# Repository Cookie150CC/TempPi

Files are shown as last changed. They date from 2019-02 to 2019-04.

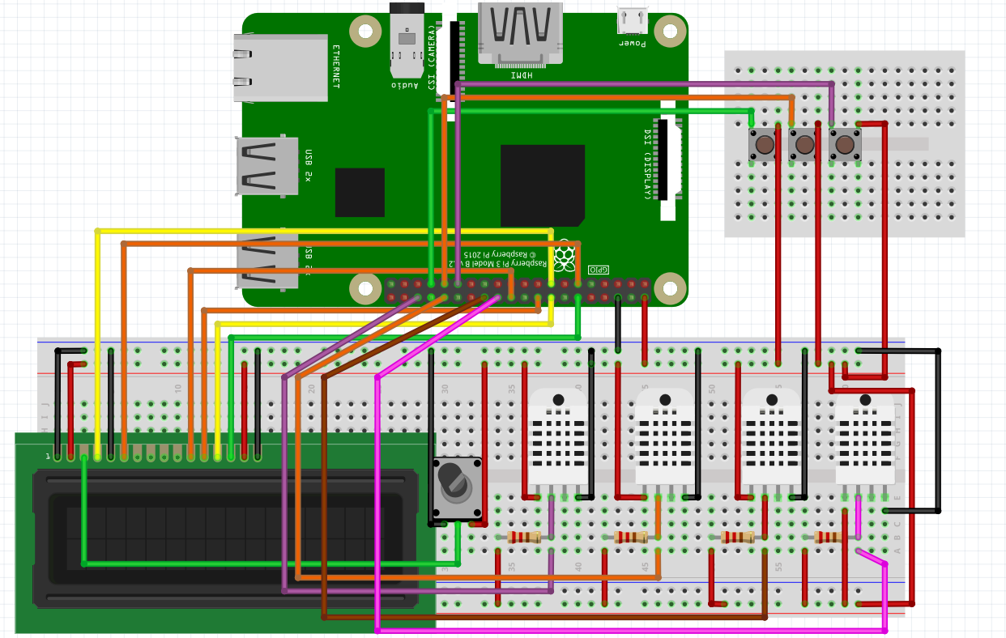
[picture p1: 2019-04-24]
Diagrams and Models/Wiring Diagram/Wiring Diagram.PNG

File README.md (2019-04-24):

# TempPi
- A server room temperature sensor system.
- This program was create for a Raspberry Pi model 3 b+

## WorkFlow
1. When adding a feature Create a new branch for your feature using "git checkout -b <name of your new branch>"
2. When done use push up your branch using "git add <name(s) of added files>" "git commit -m 'MSG'" "git push"
3. Then create a pull request to merge your changes with the master branch. [click here](https://github.com/Cookie150CC/TempPi/pulls) 
  
## Python Programming Standards
- Please read the PEP 8 programming standard before submitting any python code to the repository.
- [PEP-8 programming standard](https://www.python.org/dev/peps/pep-0008/#maximum-line-length)
- Pyhton 3 will be used exclusively

## Install
- To ensure proper functionality please clone this directory into ~/Source on the Raspberry Pi file system.
- To use the Adafruit_Python_DHT sensor library. The directory can be found [here](https://github.com/adafruit/Adafruit_Python_DHT). Then run the setup.py script to install on the Raspberry Pi
- For used wiring please reference [here](https://github.com/Cookie150CC/TempPi/blob/master/Spikes/RaspberryPi_v01_WiringSchematic.pdf) in the Spikes directory
- For real time clock integration please reference [here](https://github.com/Cookie150CC/TempPi/blob/master/Spikes/Spike%20on%20RTC%20integration.md)

## WebApp for project
- Reference [this repository](https://github.com/yillivs/Pi-Webapp).

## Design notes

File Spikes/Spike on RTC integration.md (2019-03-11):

# RTC PF8523
- [Datasheet](https://www.nxp.com/docs/en/data-sheet/PCF8523.pdf)

### For wiring, i2c configuration, setting up the pi on RTC time, and RTC time synchronization use [this](https://pimylifeup.com/raspberry-pi-rtc/) as a reference.

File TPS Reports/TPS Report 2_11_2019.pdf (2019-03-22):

TPS Report
2/11/19
Brittain Cooke
Grant Gannon
Oliver Sanchez
| Task | Time Estimate | Risk | Who | Review
| Spikes On SMS From PI | 2 Days | 4 | All | One of the project requirements is being able to send a text alert to our administrative user alerting them in the event of a temperature spike. We went and tried to find our best and most cost effective solution for this project.
| Spike on Logging Temp | 2 Days | 3 | BC | Worked on getting the PI to periodically record the ambient temperature. This too is a project requirement set by our client. It's also critical for our future web app implementation
| Integrating RTC | 2 Days | 3 | BC/OS | Integrating the Real Time Clock will allow us to track time even when the real time server it checks in with is down. The RTC will be critical for gauging blackout time which we then can log.
| Look into more case solutions | 2-4 Days | 2 | GG | At this point we're going forward with designing our case, the biggest thing to consider is how to attach the screen onto the case.
| Review Stories and TPS Reports | 1 Day | 2 | All | Keep files organized and accessible

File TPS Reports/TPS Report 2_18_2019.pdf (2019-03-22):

TPS Report
2/18/19
Brittain Cooke
Grant Gannon
Oliver Sanchez
| Task | Time Estimate | Risk | Who | Review
| Created a physical control | 2-3 Days | 3 | BC | Added some options to be added using the physical controls, this let's the user change settings without remoting in to the pi itself.
| Work on remote accessibility | 2 Days | 3 | BC | Worked on ssh functions of the project. Allowing us to remotely poll the pi for the temperature. Will be critical for future implementation of the user site.
| Spike on WebApp Design | 2 Days | 3 | OS | Working through to decide what our options are for our browser app/access. Worked on making/finding our stye guide for the site to follow. Also worked on finding a method to recieve the data from the pi to then be able to display
| Case Design | 2-4 Days | 2 | GG | Worked on a test iteration of the case design using maya Autodesk, which consisted of the housing for the PI along with mounting for the screen. The major downside is that it's still not housing all the components but not sure if this can be helped.
| Review Stories and TPS Reports | 1 Day | 2 | All | Keep files organized and accessible

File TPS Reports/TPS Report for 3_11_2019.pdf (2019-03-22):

TPS Report

3/11/19

Brittain Cooke

Grant Gannon

Oliver Sanchez

| Task | Time Estimate | Risk | Who | Review
| Permanent Wiring Solution Spike | 2 Days | 2 | GG/BC | For the final product we're going to want something nicer than a breadboard to connect our devices and sensors. A PCB is a possible alternative to sawed down breadboard.
| Case Research Cont. | 2 Days | 1 | GG/BC | The search for a case not only for the PI but the components continues. Now that final constraints are available a case is in developement
| Adding Unittesting | 2 Days | 3 | BC | Pythons unittest library has been utilized to create unit test for all funcitons. Test will be continuously added now as new funcitons are made [1]
| Converting program to object oriented approach 4 Days | | 4 | BC/OS | The program was reorganized as an OOP for readability, security, and maintanability.
| General Wiring Scematic | 1 Day | 2 | OS | After the re-wire, the need for a schematic became clear if we would want to easily make another one.
| WebApp services create | 2 Day | 2 | OS | Keep files organized and accessible. Merge development branch with our production branch. Created service classes to manage authentication tasks like retreiving authentication tokens and http requests.

### [1] sadf

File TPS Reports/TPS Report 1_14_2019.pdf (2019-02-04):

TPS Report

1/14/19

Brittain Cooke

Grant Gannon

Oliver Sanchez

| Task | Time Estimate | Risk | Who | Review
| Find a python programming standard agreeable to all | 2-4 Days | 3 | All | Important to ensure team members are all writing in same style/format
| Prep Raspberry Pi | 1 Day | 2 | BC | Get the device prepared with some simple operating system, to be able to start testing when parts arrive
| Begin research on on-campus 3d printing solutions | 1 Day | 2 | BC | Maker Spaces at library/Computer Club/Ordering
| Review Stories and TPS Reports | 1 Day | 2 | All | Keep files organized and accessible

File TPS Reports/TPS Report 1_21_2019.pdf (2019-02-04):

TPS Report
1/21/19
Brittain Cooke
Grant Gannon
Oliver Sanchez
| Task | Time Estimate | Risk | Who | Review
| Implement Screen | 1-2 Days | 4 | BC | Implement screen to raspberry pi to output basic text
| Spike on Temp Probes | 2-3 Days | 3 | All | Measure accuracy of our ordered temperature probe compared to 'actual' temperature
| Spike on PI Operating system | 1 Day | 2 | GG | Finalize our decison on what operting system to use
| Review Stories and TPS Reports | 1 Day | 2 | All | Keep files organized and accessible

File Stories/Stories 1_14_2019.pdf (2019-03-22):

Brittain Cooke
Grant Gannon
Oliver Sanchez

Stories

1) Create a device that acts as a temperature monitor for a server room: Features:
-Read room temperature using a raspberry pi and sensors -Periodically record and store temperature
-Show status using an led light based on temp
-show current temp values on the device using a display -Get humidity reading from the sensors
-AC Powered
-Connected by Wifi
2) Allow a server administrator to remotely view temps and interact with the device
Features:
-Allow an admin to SSH on to the device
-create a web app to allow users to view temperature and status -allow admin to view system logs
-be able to dump output log
-be able to modify log(add, delete, move, and search)
-be able to add and remove users from registry
3) Setup an alert system for admins if temperature exceeds limits Features:
-Send SMS text to admin when the temperature is out of range. -Allow admin to edit the thresholds for alerts
-Allow admins to edit the users to notify for these alerts
4) Create a case for the device to be contained Features:
-Make a 3D printed case to accommodate the raspberry pi

5) Device must be able to perform adequately in atypical power conditions Features:
-Device should be able to perform a safe shutdown in event of brown/blackout
-Device will reboot and log time it was offline for after a shutdown -Battery backup to ensure it can shutdown during complete blackout

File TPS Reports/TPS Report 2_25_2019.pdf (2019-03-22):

TPS Report
2/25/19
Brittain Cooke
Grant Gannon
Oliver Sanchez
| Task | Time Estimate | Risk | Who | Review
| Real Time Clock integration | 2-3 Days | 3 | BC | Real time clock added and selected to sync with Westerns time server
| Physical inteface | 2 Days | 2 | BC | Worked on overall design and control of the interface and physical interaction
| SMS over text messaging | 2 Days | 3 | All | The function to send out an email to any of the major carriers has been fleshed out all that's left is to implement into the project at large. The required information to send out a text is their phone number and carrier to be able to send out a message
| Web App | 3-4 Days | 4 | OS | Continued work on web app, currently hosted on a separate testbed could be implemented onto the PI or onto a seperate server. Styling and login services are still wip. Stpes to add users and admins have been added in.
| 3D Modeling Software | 2-4 Days | 2 | GG | Investegated other modeling software options because of the learning curve that's imposed by Maya Autodesk. Other solutions such as windows 3d builder, CAD, and blender. CAD seems like the ideal choice, but shares a lot of the challenges that Maya does. Windows 3d builder and blender don't have nice ways to implement actual scale
| Review Stories and TPS Reports | 1 Day | 2 | All | Keep files organized and accessible

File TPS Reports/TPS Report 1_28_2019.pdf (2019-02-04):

TPS Report
1/28/19
Brittain Cooke
Grant Gannon
Oliver Sanchez
| Task | Time Estimate | Risk | Who | Review
| Get Temperature to output Formatted on Screen | 2 Days | 3 | All
| Python Unit Testing Spike | 3-4 Days | 5 | All | What is it, and how do we do it: Unittest and other modules
| Implement ssh to connect with PI | 1 Day | 2 | OS | Being able to access remotely is a top priority
| Review Stories and TPS Reports | 1 Day | 2 | All | Keep files organized and accessible

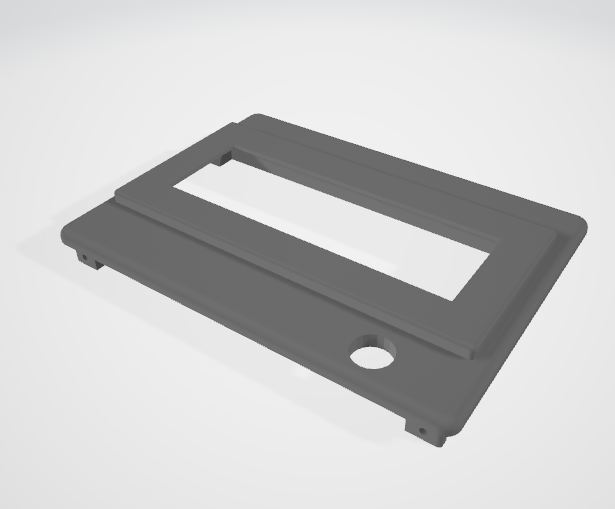
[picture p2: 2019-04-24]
Diagrams and Models/Case Design/Case Lid V2.PNG

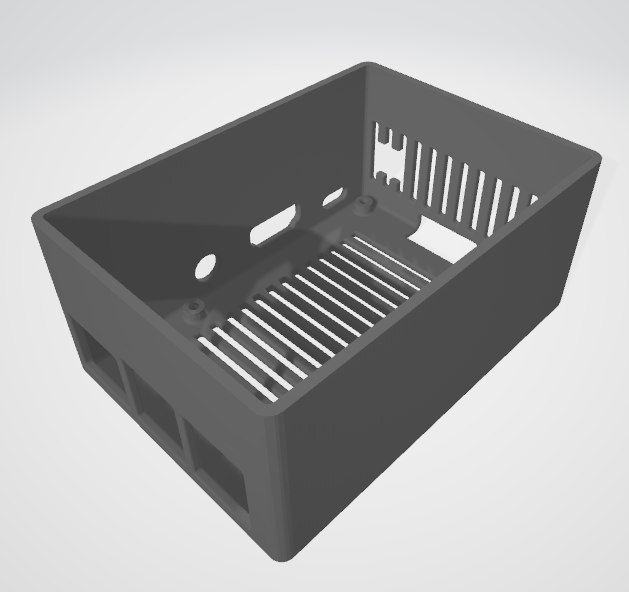
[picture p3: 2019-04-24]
Diagrams and Models/Case Design/Case Base V2.PNG

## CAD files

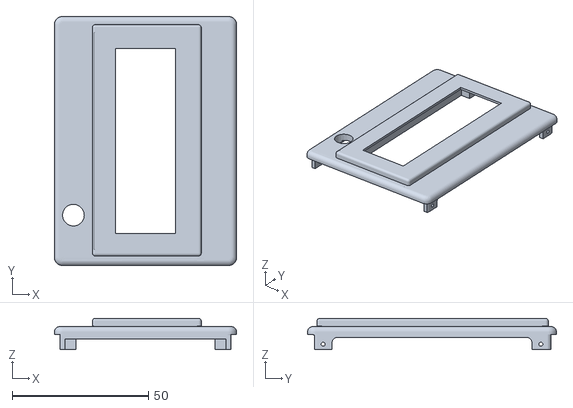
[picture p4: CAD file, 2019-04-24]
Diagrams and Models/Case Design/Case Lid V2.stl
67.0 x 91.5 x 11.5

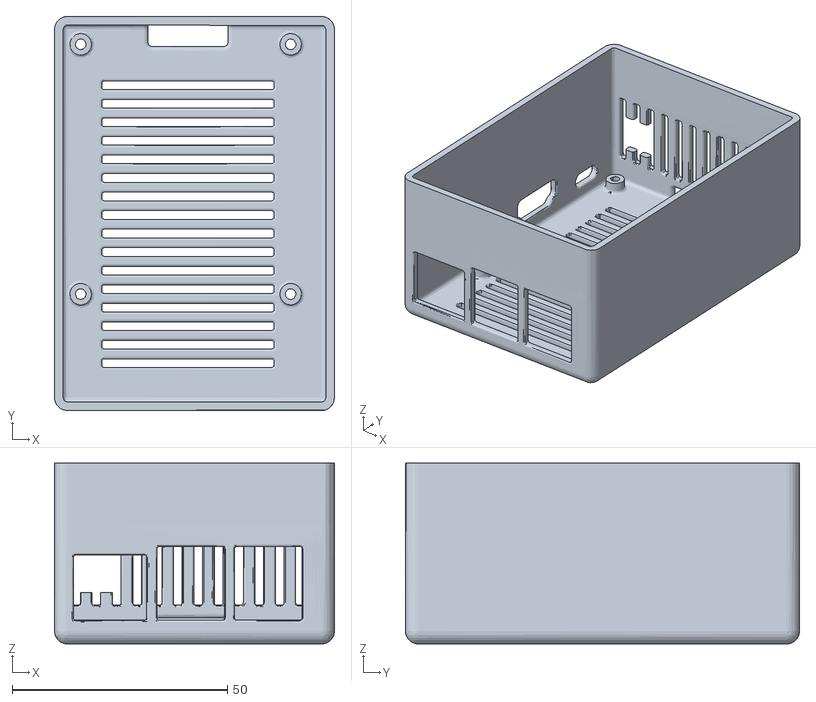
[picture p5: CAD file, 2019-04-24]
Diagrams and Models/Case Design/Case Bottom V2.stl
65.0 x 91.5 x 42.0

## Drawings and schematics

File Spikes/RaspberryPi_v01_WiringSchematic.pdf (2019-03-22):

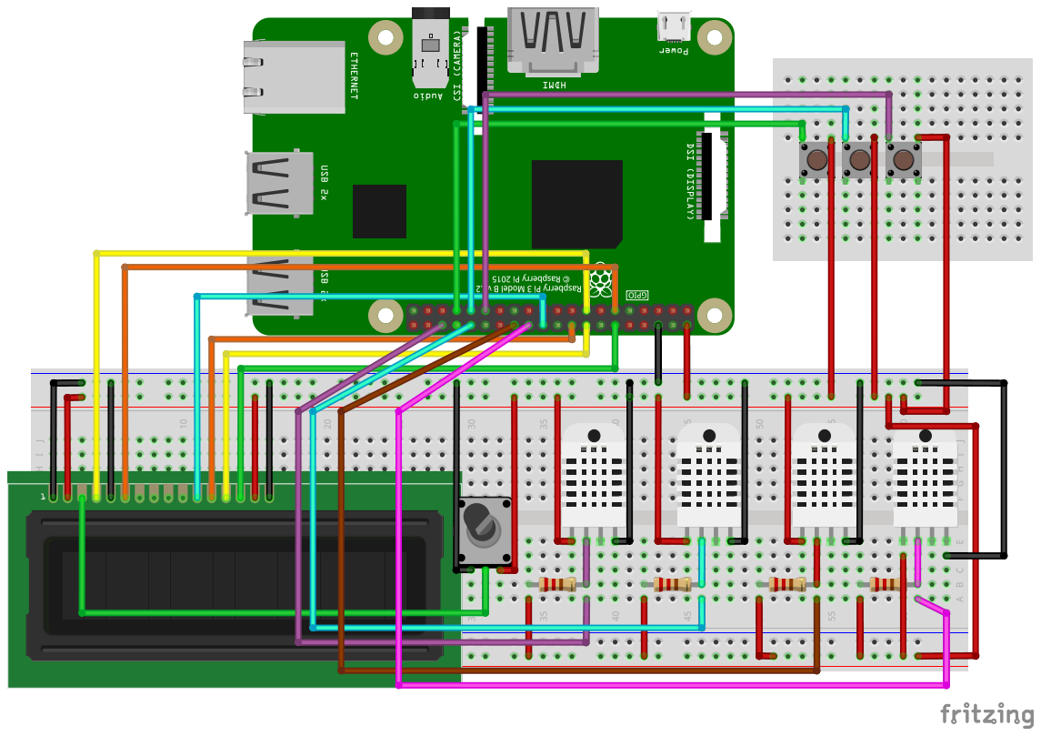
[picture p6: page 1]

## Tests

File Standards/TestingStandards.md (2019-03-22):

# Testing Standards

## Unit tests for python
- Pythons native unittest library will be used for testing of individual functions
- Documentation for pythons unittest library can be found [here](https://docs.python.org/3/library/unittest.html)
- To automate test set up the following cron job 0 0 * * * python /home/pi/Source/tests.py >> /home/pi/Source/TempPi/Source/test_logs.txt 2>&1

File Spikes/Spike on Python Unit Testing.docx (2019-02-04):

Brittain Cooke

Grant Gannon

Oliver Sanchez

Python Unit Testing

Brief: Just like in the Quad-Solver project we will need to implement some form of unit testing. For obvious reasons we will not be able to use CUnit for our python program. The goal of this spike is to identify a unit testing framework that is widely accepted, and easy to implement for our room monitoring system.

Unittest: the inbuilt python unit testing module. The good things about is that it’s supported and developed by python themselves, and it’s the recommended package by Kent Beck! The author of our Extreme Programming book. It works similar to CUnit with similar structure for testing, with the obvious difference that they’re more like python functions opposed to C(Not really a surprise though). The test still need to be predefined and aren’t usually run as one off inline commands.

Pytest: A third party solution for unit testing, the major difference between Pytest and unittest is that it’s a lot more lightweight solution. Pytest is much more a fast inline implementation, probably useful for testing a small handful of modules.The major downside with it is when it comes time for automation testing. Pytest tests aren’t really structured or made to be all strung together for large automation testing.

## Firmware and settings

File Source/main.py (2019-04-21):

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
#    You should have received a copy of the GNU General Public License
#    along with this program.  If not, see <http://www.gnu.org/licenses/>.
__author__ = "Brittain Cooke"

#imports
import sys
import RPi.GPIO as GPIO
import LiquidCrystalPi as lcrys
import time as time 
import datetime
import socket
import threading

import Config
import TSensor
import Messenger
import Display

#Varables and declarations

configObj = Config.Config()
configObj.openJSON()
tSensorObj = TSensor.TSensor()
messengerObj = Messenger.Messenger()
displayObj = Display.Display()
option = 0  #display option 
threshold = configObj.threshold  # temp threshold
oldIP = '0.0.0.0' #Default IP
logInterval = configObj.logInterval# Number of seconds between logs
sendFlag = True # Use to send temp alert messages with a break in between
sendInterval = configObj.sendInterval *60 # Number of seconds between sending temp alearts

#General GPIO Setup
GPIO.setmode(GPIO.BOARD)
GPIO.setwarnings(False)

#LCD setup
lcd = lcrys.LCD(15, 11, 22, 18, 16, 12)
lcd.begin(16,2)

#button
def buttonPress(channel):
    global option 
    option += 1
    if option >3:
        option =0

#Button setup
GPIO.setup(31, GPIO.IN, pull_up_down= GPIO.PUD_UP)
GPIO.add_event_detect(31, GPIO.FALLING, callback=buttonPress, bouncetime=400)

#logs
def writeLogs(tSensorObj):
    t,h = tSensorObj.getAvgTemp()
    dT = datetime.datetime.now()
    with open("/home/pi/Source/TempPi/Source/temp_logs.txt", "a+") as logs:
        logs.write(dT.strftime("%Y-%m-%d %H:%M:%S | "))
        if t is not None and h is not None:
            logs.write('Temp={0:0.1f}*F, Humidity={1:0.1f}%\n'.format(t,h))
        else:        
            logs.write('Failed to get reading.')
    threading.Timer(logInterval, writeLogs,[tSensorObj]).start()

#Main Loop
def doMain():

    if isinstance(threading.current_thread(), threading._MainThread): #Main thread only
        while True:
            t,h = tSensorObj.getAvgTemp()
    
            if option == 0: #Avg Temp
                msg = [t,h]
                displayObj.doDisplayOptions(option,msg)
            elif option == 1: #Sensor 0 Temp
                t,h = tSensorObj.getTemp(0)
                msg = [t,h,0]
                displayObj.doDisplayOptions(option,msg)
            elif option == 2: #Sensor 1 Temp
                t,h = tSensorObj.getTemp(1)
                msg = [t,h,1]
                displayObj.doDisplayOptions(option,msg)
            elif option == 3: #IP
                msg = [oldIP]
                displayObj.doDisplayOptions(option,msg)
        
            global sendFlag
            if t > threshold and sendFlag is True:
                messengerObj.sendMsg(configObj,t)
                sendFlag = False
                threading.Timer(sendInterval, doMain).start()   
    
    if not isinstance(threading.current_thread(), threading._MainThread): #Child thread only
        sendFlag = True


# End of main loop

writeLogs(tSensorObj)#Start logs writing
doMain()#Start main display loop

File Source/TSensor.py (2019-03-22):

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
# The program is made to use DHT22 temperature sensors

#This Library is made by Adafruit under the MIT liscense. The code can be found at https://github.com/adafruit/Adafruit_Python_DHT
import Adafruit_DHT as _dht


class TSensor():
 
    #DHT setup
    sensor = _dht.DHT22
    pins = [16, 12]

    #Do temp reading of specified sensor
    def getTemp(self, pTSensor):
        h0, t0 = _dht.read_retry(self.sensor, self.pins[pTSensor])
        if t0 is not None and h0 is not None:
            t0 = t0 * 9/5.0 + 32

        return t0,h0

    #Get an average temp
    def getAvgTemp(self):
        
        h0, t0 = _dht.read_retry(self.sensor, self.pins[0])
        h1, t1 = _dht.read_retry(self.sensor, self.pins[1])
        if t0 is not None and h0 is not None and t1 is not None and h1 is not None:
            hAvg = (h0+h1)/2
            tAvg = (t0+t1)/2
            #For Farenheit vvvv Comment out for Celcius
            tAvg = tAvg * 9/5.0 + 32
        else:
            hAvg = None
            tAvg = None
        
        return tAvg, hAvg

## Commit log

2019-02-25 Current Temp Beta
2019-03-11 General program imporvement, Use of individual sensors
2019-03-13 Uploaded wiring schematic
2019-04-10 Timer and log thread added. Update to use a json file
2019-04-21 Updated finally push for threading and Message Changes
2019-04-24 Case and Diagram
    Added the case and diagram stl and fzz files along with sample images of each,
    [Case Bottom V2.stl, Case Lid V2.stl, RaspberryPi_v01.fzz]

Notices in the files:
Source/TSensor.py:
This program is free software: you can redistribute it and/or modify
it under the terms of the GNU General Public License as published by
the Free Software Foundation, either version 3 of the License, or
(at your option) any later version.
